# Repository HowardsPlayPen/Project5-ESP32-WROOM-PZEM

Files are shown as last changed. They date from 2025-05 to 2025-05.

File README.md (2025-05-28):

# Project 5: ESP32WROOM + some SMD soldering

So far, all my projects had involved modules for each component, such as using an ESP32-CAM, but I wanted to move to use more compact components - such as the ESP32-S2. The camera on the ESP32-CAM is amazing and simple to use - but for most of the projects I wanted to build having more GPIO pins available seemed like a better option.

At this point a friend sent me the following [link](https://twitter.com/i/status/1598419769077952512) showing an amazing PCB that was not much thicker than the PCB board but with a wonderul TFT screen built in

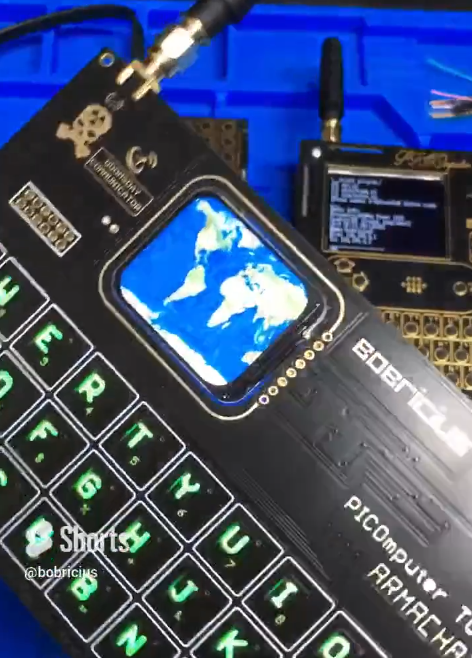
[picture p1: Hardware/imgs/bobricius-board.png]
Bobricus board


The twitter feed included a link to where you can buy the TFT on [AliExpress](https://www.aliexpress.com/item/1005003768946439.html)

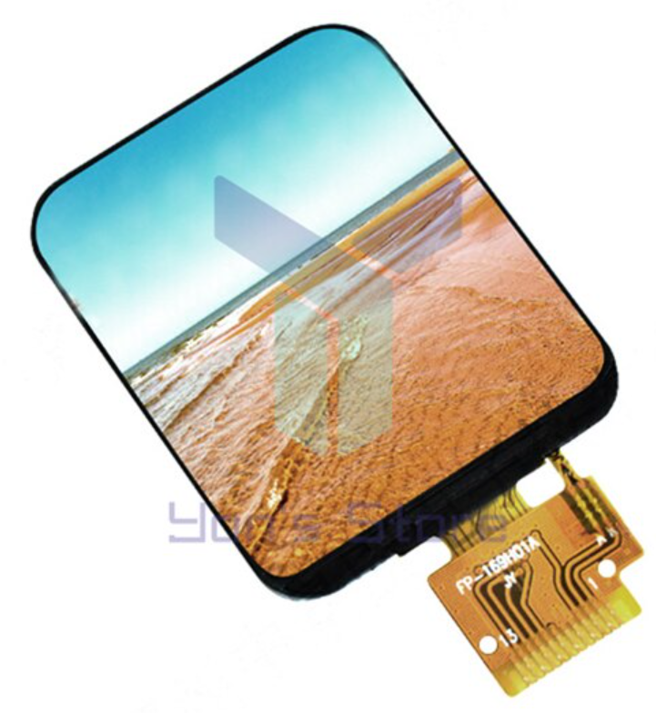
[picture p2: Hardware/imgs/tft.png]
TFT screen


Specs: 240*280 RGB Build-in ST7789 Driver Serial IPS Display

Note: this is **WAY** better than the SSD1306 I have been using which is a 0.96' screen 128x64 single colour screen

I wanted to try out these screens but I haven't soldered FPC cables before and so I bought several of these and one module that breaks out the wires into standard 2.54 mm pins. This way I could test the board to know it drives the panel ok before worrying about the FPC side

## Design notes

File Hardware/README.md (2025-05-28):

# Project5-ESP32-WROOM

Using an ESP32-WROOM + RFM69HW + PZEM + pinouts for a few different LED screens.

## Aim

Test out various different circuits - including touch buttons connected to ESP32 pins (I read that they could work as capacitative buttons)

It includes a connector for PZEM - i.e. ability to monitor 240V power use.

### PZEM v3
I bought my PZEM from Aliexpress but they are available everywhere, eg. [see here](https://esphome.io/components/sensor/pzemac.html)

PZEM v3 Board

## NOTE about OLED screen / board

> Note: this board does not connect BLK to 3V as the documentation said it was optional. This PCB works for the ST7789V2 boards that I have, but does not work for a newer ST7789V3 board where it **NEEDS**  BLK to be connected to 3V.

### Kicad Rendering of the PCB

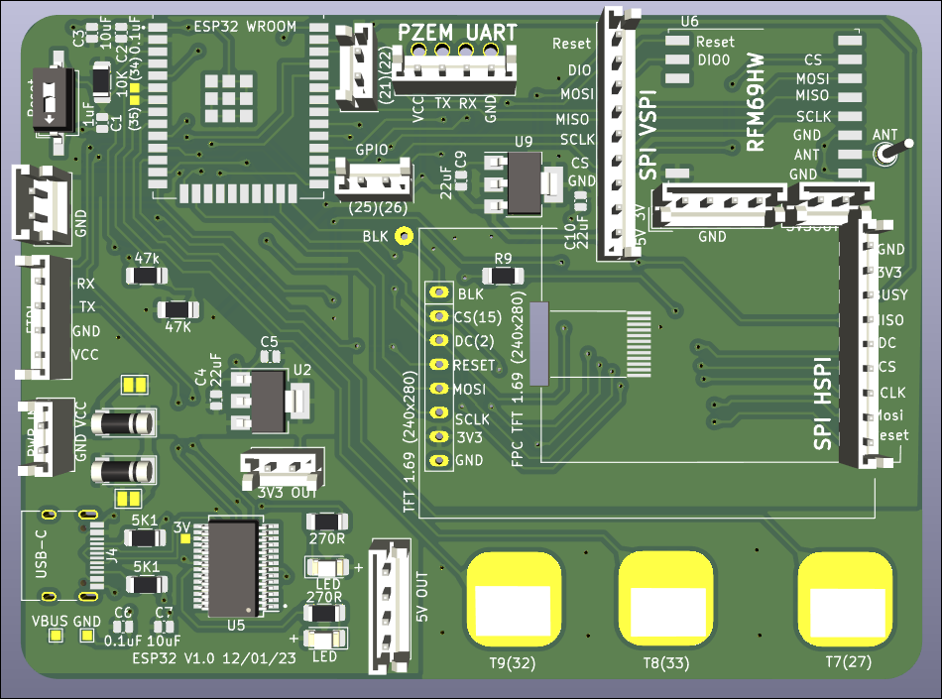
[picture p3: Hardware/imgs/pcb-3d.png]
Kicad rendered view of Finished board


### Kicad view of the PCB

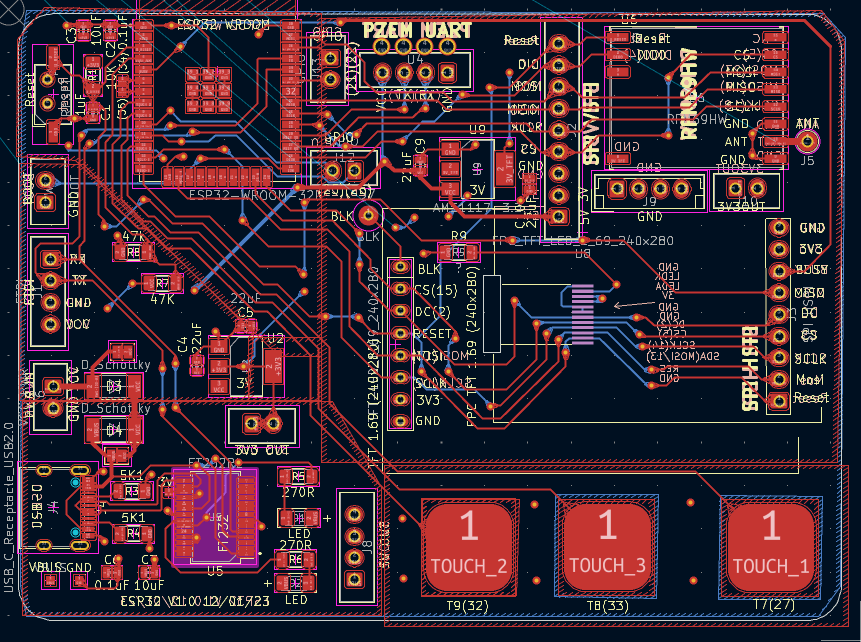
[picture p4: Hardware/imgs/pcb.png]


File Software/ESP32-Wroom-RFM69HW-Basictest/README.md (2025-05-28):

# Basic tests to evidence that the RFM69HW is connected properly to the board

For the RFM69HW to be working, it needs
1. power
2. correct wiring - e.g. GPIO  / hardware SPI (fallback to SPI is possible if I got the wiring wrong)
3. Reset working - currently should be connected to ESP32 reset on startup

At a software level, there is the choice of RFM69 library - I favour the RFM69 library by Felix Rusu ( https://github.com/LowPowerLab ) as I used it previously with Atmel examples, but the documentation states that the support of ESP32 is a best effort basis supported by separate developers (so I am not sure what to expect). I could also use the MySensors library (https://github.com/mysensors )- but at first glance I have not been filled with confidence that it will provide a library that is usable (only in that it is there to fulfil a purpose and if that purpose is not what you want then it did not feel as if the documentation was good enough to show you the best way to do things). Anyway, we shall soon see.....

Initially this project will test the Felix Rusu library and see how it works (or not..)

This project is working on the basis that earlier projects have been shown to work - e.g. wiring should be good + TFT screen is operational. This means that we can display lots of debug diagnostics on the screen to assist in establishing whether it all works.

## Project update

The first board I soldered was tested incrementally

1. first that the supporting circuitry worked - e.g power regulators / USB-C pins (these were crazy to solder!) - this was fine
2. add the ESP32 WROOM and check that it starts up with output being fed to RX / TX and that it can be flashed with new software - this worked fine
3. added the TFT screen and checked that worked (this uses the ESP32 hardware SPI of HSPI)  - this worked fine (so hence on to this Project to add the RFM69HW and test it)
4. adding the RFM69HW to the board - at this point the results started to go awry. The TFT screen did not work and neither did the RFM69HW - but the ESP32 was working perfectly fine 

I tried to debug the issue in both software and electronically but it was not obvious which element was causing the issue

1. it wasn't likely to be power related - i.e. if the RFM69HW was shorted or causing the voltage to dip too much then it is unlikely the ESP32 would work - so as the ESP32 was working I did not think this was the issue
2. the SPI pinouts were unconnected - e.g. using VSPI for RFM69HW and HSPI for TFT Screen so I could not see how adding the RFM69 could cause the previously working TFT to stop working (i.e. by having one wire cause a conflict)

I decided to solder up another board, both for practice but also with the aim to incrementally build it up again and see if the problem is replicated + at the same stage having the second board would also be useful if / when it was working, as one needs to have a test using **two** boards to see something transmit and something receive.

The second board worked better than the first
1. the first board did not play well with the software project - i.e. as a test I added a call to radio->readRegs() which should read all the contents of the RFM69 registers over SPI and dump them - but all it dumped were zero's. The second board dumped the following (showing an SPI  connection was seemingly working)

```
Address - HEX - BIN
1 - 4 - 100
2 - 0 - 0
3 - 2 - 10
4 - 40 - 1000000
5 - 3 - 11
6 - 33 - 110011
7 - 6C - 1101100
8 - 40 - 1000000
9 - 0 - 0
A - 41 - 1000001
B - 40 - 1000000
C - 2 - 10
D - 92 - 10010010
E - F5 - 11110101
F - 20 - 100000
10 - 24 - 100100
11 - 7F - 1111111
12 - 9 - 1001
13 - F - 1111
14 - 40 - 1000000
15 - B0 - 10110000
16 - 7B - 1111011
17 - 9B - 10011011
18 - 8 - 1000
19 - 42 - 1000010
1A - 8A - 10001010
1B - 40 - 1000000
1C - 80 - 10000000
1D - 6 - 110
1E - 10 - 10000
```
2. The TFT screen worked, even whilst the RFM69 was connected and operating (as shown above)

3. I tried to test the second board by flashing a transmitter test to an old Moteino board - which should ideally show some activity on my new ESP32 board + software Project, but I could not get any sign that it was transmitting or receiving anything. A simple call on the ESP32 to 

`radio->sendWithRetry(2, "START", 5,0,0);`

testing if the board would transmit did not work as expected as it never returned from this call (at least not in the 5 mins that I waited). 

**at this point (for now) I have decided to go down a different tack and order some new RA-01 Lora boards + update the PCB design to incorporate all the design issues + incorporate some new learning. I realise that I can spend a long time figuring out what is wrong - but in this case all I want is to get a LORA board working with an ESP32 and 'maybe' the better idea is to use a newer component (after all I have had the RFM68HW lying around for >5 years so maybe I should move on)**

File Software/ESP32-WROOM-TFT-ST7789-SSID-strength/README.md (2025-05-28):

# Purpose of this project is to test out the 1.69' TFT screen

Previous projects have helped to confirm whether the GPIO pins are correctly soldered  (and that the ESP32 is operational). 
This project includes the breakout version of the 1.69' TFT 240x RGB https://www.aliexpress.com/item/1005003754253714.html

It will help test:
1. whether all the pins for the TFT are correctly wired + soldered
2. are they correctly configured for the hardware SPI port of the ESP32 **VSPI**
3. once it is proven that we can use the hardware SPI VSPI then the included graphics tests (copied from Adafruit example) demonstrate various text drawing / line drawing routines

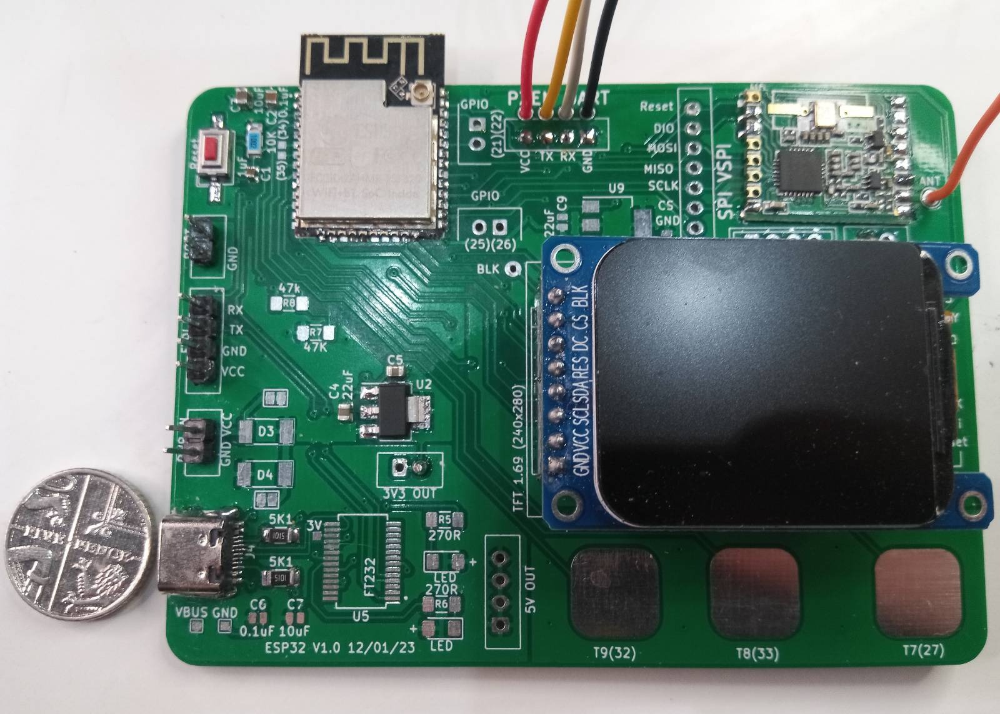
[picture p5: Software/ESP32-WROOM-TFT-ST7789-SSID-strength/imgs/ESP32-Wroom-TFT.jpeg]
Populated board ESP32 Board with mounted 1.69' TFT 240x280


**Once this project is working the board is known to have a working TFT, it can be used to display debug information for the next project.**

## Project update

The screen is an amazing screen and gives the ESP32 board a great way of displaying a weath of information in a rich way - far better than the .96' single colour TFT screen I used to use. By using the board version of the display I now have a working version to use as a benchmark - i.e. I can see how it is designed to hold the FPC display and what driving circuitry it uses. It also means that I know the circuit WILL work when I use the FPC TFT - i.e. always start from a known working premise (rtaher than use a never tested FPC TFT and then have too many unknowns when testing).

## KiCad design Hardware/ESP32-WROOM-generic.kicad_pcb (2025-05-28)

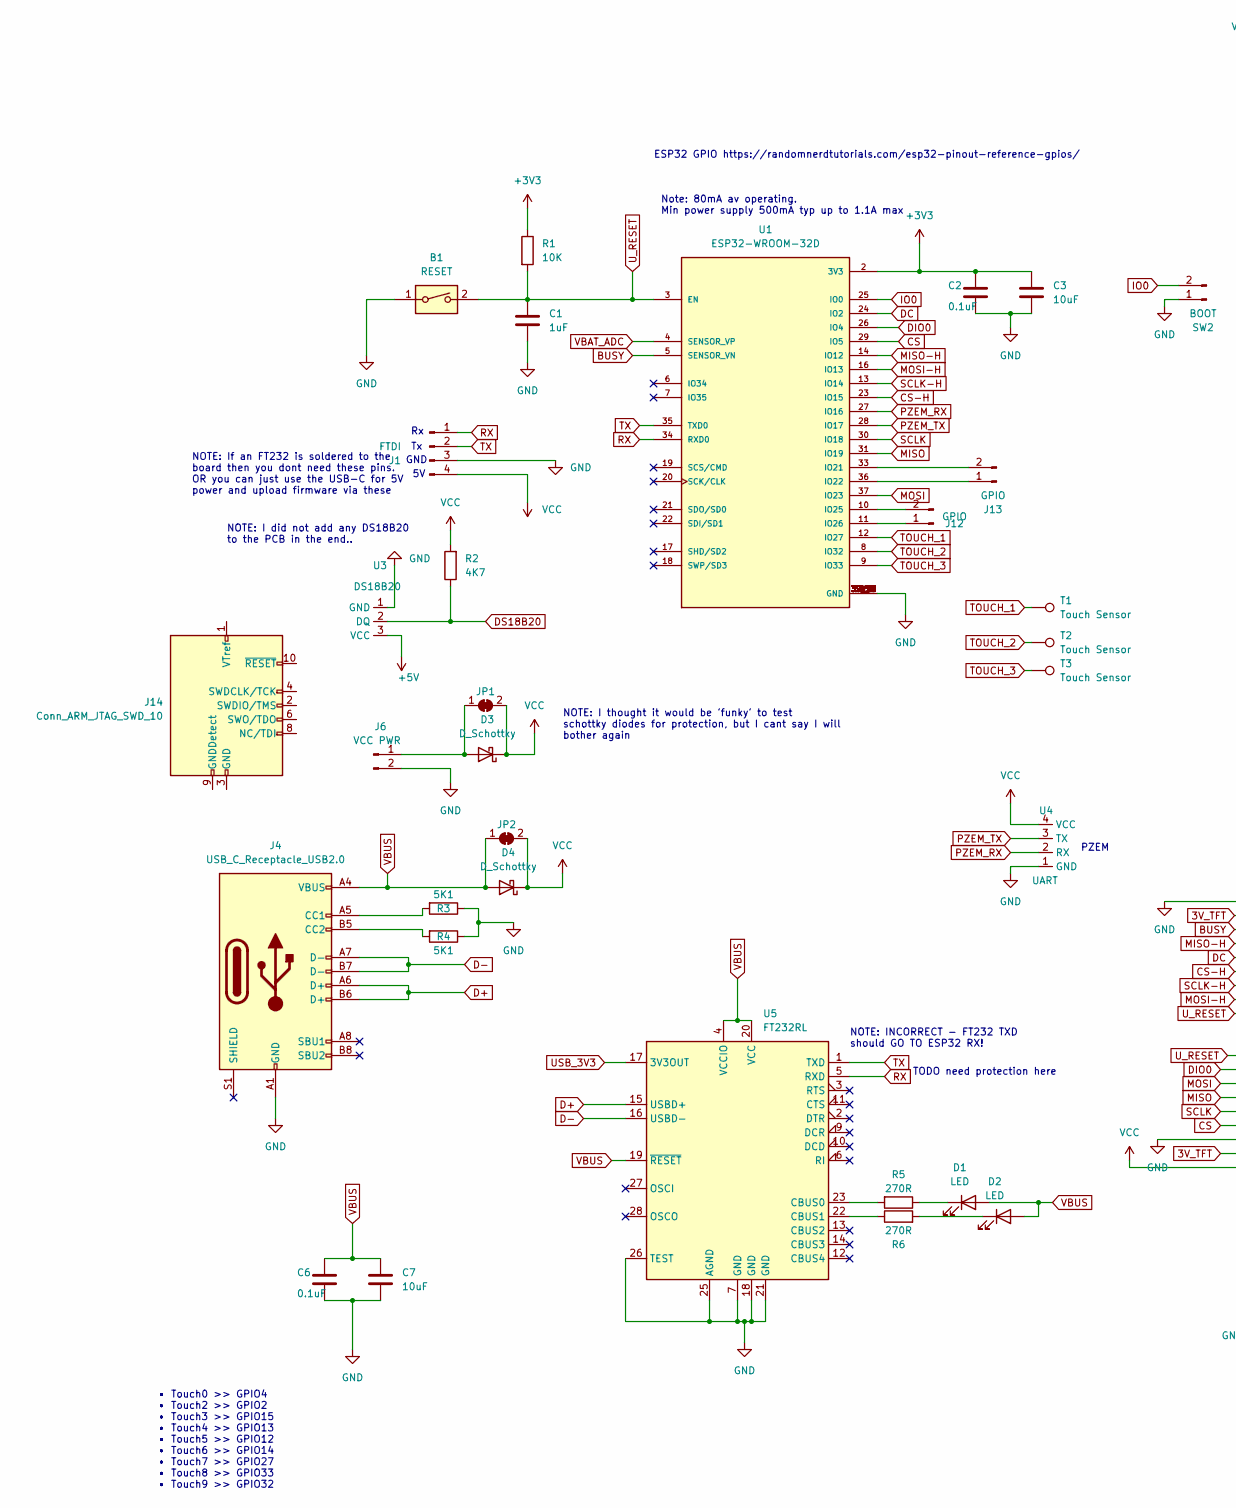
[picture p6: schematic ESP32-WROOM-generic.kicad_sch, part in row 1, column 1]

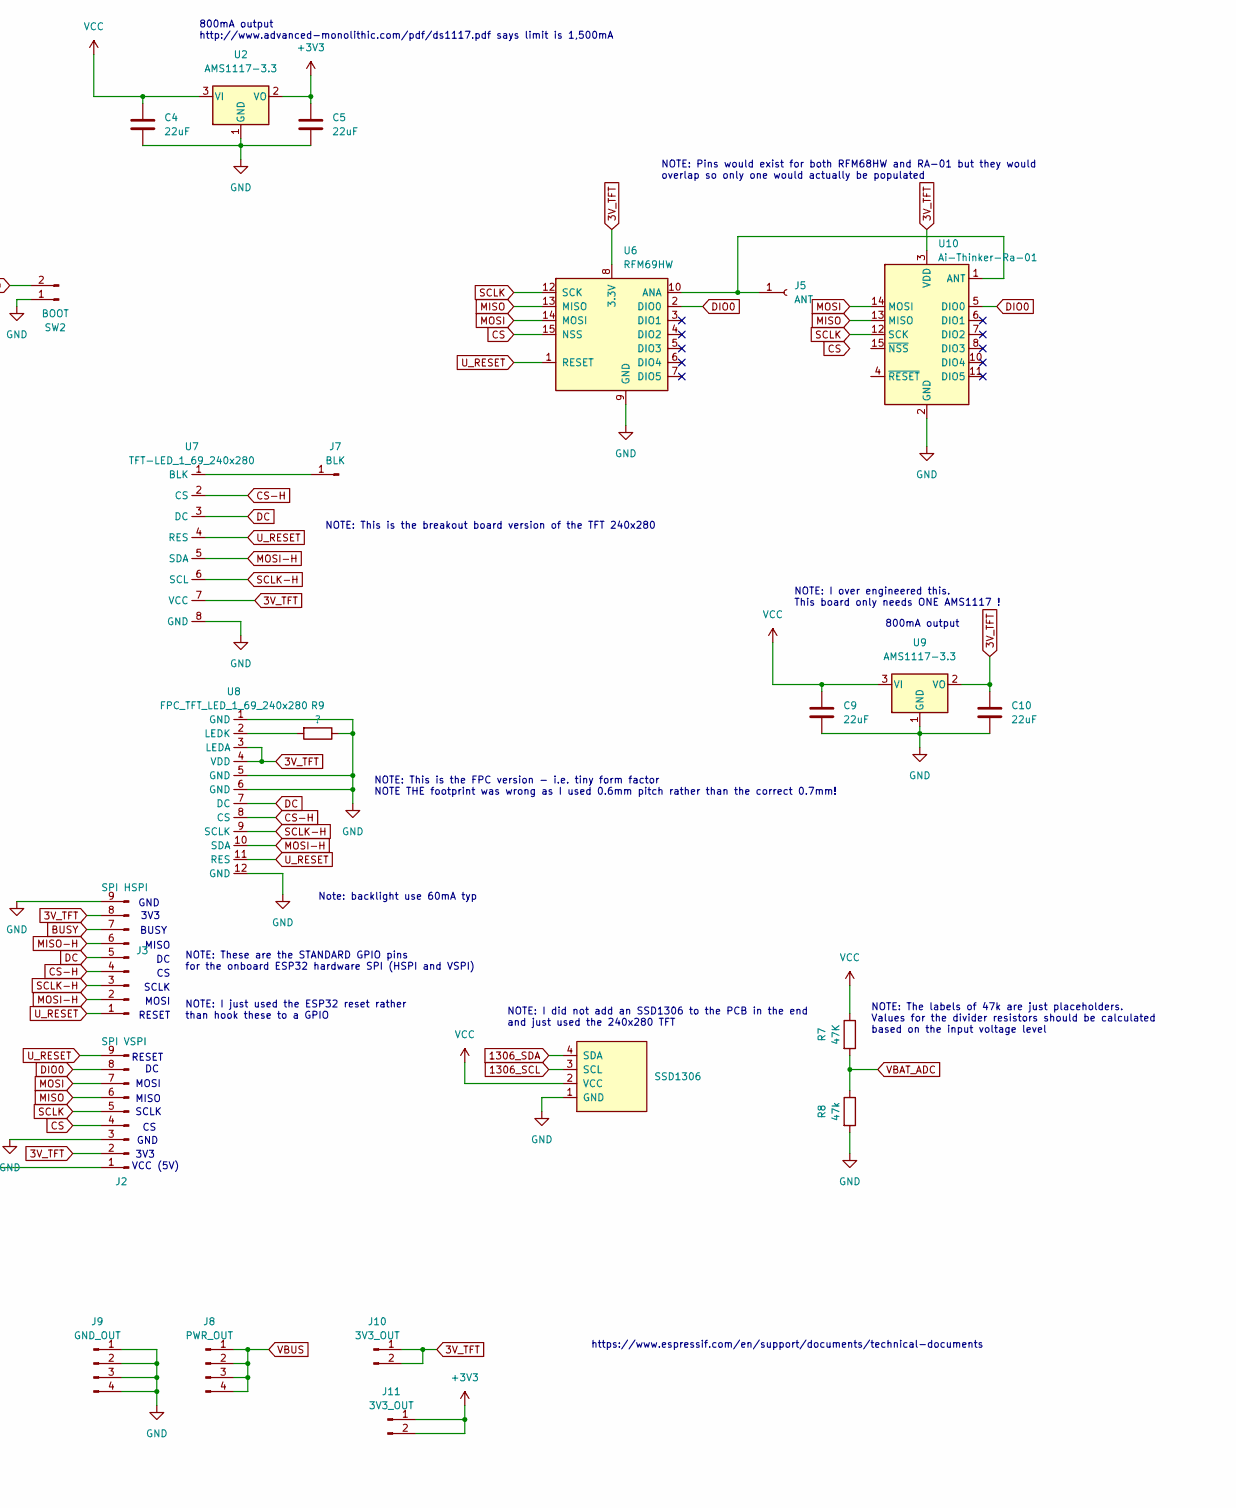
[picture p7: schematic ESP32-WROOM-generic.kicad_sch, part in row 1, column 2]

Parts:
B1: RESET; SW_DIP_SPSTx01_Slide_6.7x4.1mm_W8.61mm_P2.54mm_LowProfile
Brd1: SSD1306; 128x64OLED
C1: 1uF; C_0504_1310Metric_Pad0.83x1.28mm_HandSolder
C2, C6: 0.1uF; C_0504_1310Metric_Pad0.83x1.28mm_HandSolder
C3, C7: 10uF; C_0504_1310Metric_Pad0.83x1.28mm_HandSolder
C4, C5, C9, C10: 22uF; C_0504_1310Metric_Pad0.83x1.28mm_HandSolder
D1, D2: LED; LED_1206_3216Metric_Pad1.42x1.75mm_HandSolder
D3, D4: D_Schottky; D_MELF
J1: FTDI; JST_EH_B4B-EH-A_1x04_P2.50mm_Vertical
J2: SPI VSPI; JST_EH_B9B-EH-A_1x09_P2.50mm_Vertical
J3: SPI HSPI; JST_EH_B9B-EH-A_1x09_P2.50mm_Vertical
J4: USB_C_Receptacle_USB2.0; USB_C_Receptacle_HRO_TYPE-C-31-M-12
J5: ANT; Pin_D1.0mm_L10.0mm
J6: VCC PWR; JST_EH_B2B-EH-A_1x02_P2.50mm_Vertical
J7: BLK; TestPoint_Plated_Hole_D2.0mm
J8: PWR_OUT; JST_EH_B4B-EH-A_1x04_P2.50mm_Vertical
J9: GND_OUT; JST_EH_B4B-EH-A_1x04_P2.50mm_Vertical
J10, J11: 3V3_OUT; JST_EH_B2B-EH-A_1x02_P2.50mm_Vertical
J12, J13: GPIO; JST_EH_B2B-EH-A_1x02_P2.50mm_Vertical
J14: Conn_ARM_JTAG_SWD_10
JP1, JP2: SolderJumper_2_Bridged; SolderJumper-2_P1.3mm_Bridged_Pad1.0x1.5mm
R1: 10K; R_1206_3216Metric_Pad1.30x1.75mm_HandSolder
R2: 4K7; R_1206_3216Metric_Pad1.30x1.75mm_HandSolder
R3, R4: 5K1; R_1206_3216Metric_Pad1.30x1.75mm_HandSolder
R5, R6: 270R; R_1206_3216Metric_Pad1.30x1.75mm_HandSolder
R7: 47K; R_1206_3216Metric_Pad1.30x1.75mm_HandSolder
R8: 47k; R_1206_3216Metric_Pad1.30x1.75mm_HandSolder
R9: ?; R_1206_3216Metric_Pad1.30x1.75mm_HandSolder
SW2: BOOT; JST_EH_B2B-EH-A_1x02_P2.50mm_Vertical
T1, T2, T3: Touch Sensor; TestPoint_Pad_D4.0mm
U1: ESP32-WROOM-32D; MODULE_ESP32-WROOM-32D; PARTREV 1.9
U2, U9: AMS1117-3.3; SOT-223-3_TabPin2
U3: DS18B20; JST_NV_B03P-NV_1x03_P5.00mm_Vertical
U4: UART; JST_EH_B4B-EH-A_1x04_P2.50mm_Vertical
U5: FT232RL; SSOP-28_5.3x10.2mm_P0.65mm
U6: RFM69HW; HOPERF_RFM69HW
U7: TFT-LED_1_69_240x280
U8: FPC_TFT_LED_1_69_240x280; FPC_TFT_1_69_240x280
U10: Ai-Thinker-Ra-01; Ai-Thinker-Ra-01-LoRa

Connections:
3V_TFT: C10.1, J2.2, J3.8, J10.1, J10.2, U6.8 (3.3V), U7.7 (VCC), U8.3 (LEDA), U8.4 (VDD), U9.2 (VO), U10.3 (VDD)
+3V3: C2.1, C3.1, C5.1, J11.1, J11.2, R1.1, U1.2 (3V3), U2.2 (VO)
BUSY: J3.7, U1.5 (SENSOR_VN)
CS: J2.4, U1.29 (IO5), U6.15 (NSS)
CS-H: J3.4, U1.23 (IO15), U7.2 (CS), U8.8 (CS)
D+: J4.A6 (D+), J4.B6 (D+), U5.15 (USBD+)
D-: J4.A7 (D-), J4.B7 (D-), U5.16 (USBD-)
DC: J3.5, U1.24 (IO2), U7.3 (DC), U8.7 (DC)
DIO0: J2.8, U1.26 (IO4), U6.2 (DIO0), U10.5 (DIO0)
GND: B1.1, Brd1.1 (GND), C1.2, C2.2, C3.2, C4.2, C5.2, C6.2, C7.2, C9.2, C10.2, J1.3, J2.3, J3.9, J4.A1 (GND), J4.A12 (GND), J4.B1 (GND), J4.B12 (GND), J6.2, J9.1, J9.2, J9.3, J9.4, R3.1, R4.1, R8.2, R9.1, SW2.1, U1.1 (GND), U1.15 (GND), U1.38 (GND), U1.39_1 (GND), U1.39_2 (GND), U1.39_3 (GND), U1.39_4 (GND), U1.39_5 (GND), U1.39_6 (GND), U1.39_7 (GND), U1.39_8 (GND), U1.39_9 (GND), U1.39_10 (GND), U1.39_11 (GND), U1.39_12 (GND), U1.39_13 (GND), U1.39_14 (GND), U1.39_15 (GND), U1.39_16 (GND), U1.39_17 (GND), U1.39_18 (GND), U1.39_19 (GND), U1.39_20 (GND), U1.39_21 (GND), U2.1 (GND), U3.1 (GND), U4.1 (GND), U5.7 (GND), U5.18 (GND), U5.21 (GND), U5.25 (AGND), U5.26 (TEST), U6.9 (GND), U6.11 (GND), U7.8 (GND), U8.1 (GND), U8.5 (GND), U8.6 (GND), U8.12 (GND), U9.1 (GND), U10.2 (GND), U10.9 (GND), U10.16 (GND); also elsewhere on the board
IO0: SW2.2, U1.25 (IO0)
MISO: J2.6, U1.31 (IO19), U6.13 (MISO), U10.13 (MISO)
MISO-H: J3.6, U1.14 (IO12)
MOSI: J2.7, U1.37 (IO23), U6.14 (MOSI), U10.14 (MOSI)
MOSI-H: J3.2, U1.16 (IO13), U7.5 (SDA), U8.10 (SDA)
unnamed: D1.1 (K), R5.1
unnamed: D2.1 (K), R6.2
unnamed: D3.2 (A), J6.1, JP1.1 (A)
unnamed: J4.A5 (CC1), R3.2
unnamed: J4.B5 (CC2), R4.2
unnamed: J5.1, U6.10 (ANA), U10.1 (ANT)
unnamed: J7.1, U7.1 (BLK)
unnamed: J12.1, U1.11 (IO26)
unnamed: J12.2, U1.10 (IO25)
unnamed: J13.1, U1.36 (IO22)
unnamed: J13.2, U1.33 (IO21)
unnamed: J14.3 (GND), J14.5 (GND)
unnamed: R2.1, U3.2 (DQ)
unnamed: R5.2, U5.23 (CBUS0)
unnamed: R6.1, U5.22 (CBUS1)
unnamed: R9.2, U8.2 (LEDK)
PZEM_RX: U1.27 (IO16), U4.2 (RX)
PZEM_TX: U1.28 (IO17), U4.3 (TX)
RX: J1.1, U1.34 (RXD0), U5.5 (RXD)
SCLK: J2.5, U1.30 (IO18), U6.12 (SCK), U10.12 (SCK)
SCLK-H: J3.3, U1.13 (IO14), U7.6 (SCL), U8.9 (SCLK)
TOUCH_1: T1.1, U1.12 (IO27)
TOUCH_2: T2.1, U1.8 (IO32)
TOUCH_3: T3.1, U1.9 (IO33)
TX: J1.2, U1.35 (TXD0), U5.1 (TXD)
USB_3V3: U5.17 (3V3OUT)
U_RESET: B1.2, C1.1, J2.9, J3.1, R1.2, U1.3 (EN), U6.1 (RESET), U7.4 (RES), U8.11 (RES)
VBAT_ADC: R7.2, R8.1, U1.4 (SENSOR_VP)
VBUS: C6.1, C7.1, D1.2 (A), D2.2 (A), D4.2 (A), J4.A4 (VBUS), J4.A9 (VBUS), J4.B4 (VBUS), J4.B9 (VBUS), J8.1, J8.2, J8.3, J8.4, JP2.1 (A), U5.4 (VCCIO), U5.19 (~RESET), U5.20 (VCC); also elsewhere on the board
VCC: Brd1.2 (VCC), C4.1, C9.1, D3.1 (K), D4.1 (K), J1.4, J2.1, JP1.2 (B), JP2.2 (B), R2.2, R7.1, U2.3 (VI), U4.4 (VCC), U9.3 (VI)

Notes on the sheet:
RESET
NOTE: I over engineered this. This board only needs ONE AMS1117 !
Note: backlight use 60mA typ
NOTE: If an FT232 is soldered to the board then you dont need these pins. OR you can just use the USB-C for 5V power and upload firmware via these
NOTE: This is the FPC version - i.e. tiny form factor NOTE THE footprint was wrong as I used 0.6mm pitch rather than the correct 0.7mm!
NOTE: The labels of 47k are just placeholders. Values for the divider resistors should be calculated based on the input voltage level
NOTE: These are the STANDARD GPIO pins for the onboard ESP32 hardware SPI (HSPI and VSPI)
NOTE: I did not add any DS18B20 to the PCB in the end..
VCC (5V)
MOSI
ESP32 GPIO https://randomnerdtutorials.com/esp32-pinout-reference-gpios/
• Touch0 >> GPIO4 • Touch2 >> GPIO2 • Touch3 >> GPIO15 • Touch4 >> GPIO13 • Touch5 >> GPIO12 • Touch6 >> GPIO14 • Touch7 >> GPIO27 • Touch8 >> GPIO33 • Touch9 >> GPIO32
MISO
800mA output http://www.advanced-monolithic.com/pdf/ds1117.pdf says limit is 1,500mA
GND
3V3
TODO need protection here
NOTE: I thought it would be 'funky' to test schottky diodes for protection, but I cant say I will bother again
NOTE: Pins would exist for both RFM68HW and RA-01 but they would overlap so only one would actually be populated
800mA output
SCLK
NOTE: I did not add an SSD1306 to the PCB in the end and just used the 240x280 TFT
NOTE: INCORRECT - FT232 TXD should GO TO ESP32 RX!
NOTE: This is the breakout board version of the TFT 240x280
PZEM
Note: 80mA av operating. Min power supply 500mA typ up to 1.1A max
https://www.espressif.com/en/support/documents/technical-documents
NOTE: I just used the ESP32 reset rather than hook these to a GPIO
BUSY

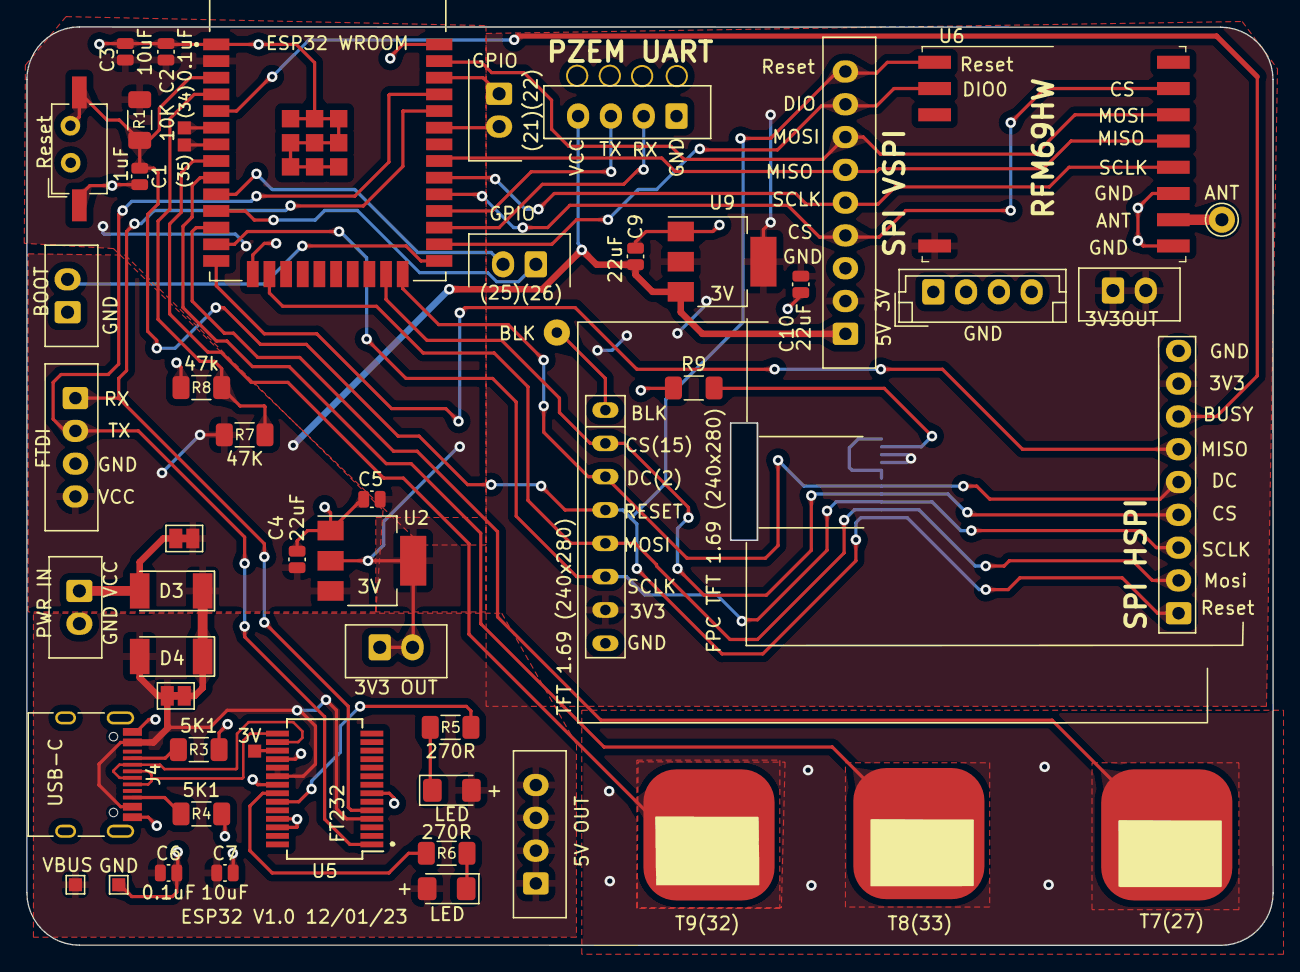
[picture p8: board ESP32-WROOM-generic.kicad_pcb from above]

Board: 2 copper layers, 95.0 x 70.0 mm, 51 parts (0 on the bottom side), 42 nets.

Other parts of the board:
GND: TestPoint_Pad_1.0x1.0mm
VBUS: TestPoint_Pad_1.0x1.0mm

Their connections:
GND: GND.1; also elsewhere on the board
VBUS: VBUS.1; also elsewhere on the board

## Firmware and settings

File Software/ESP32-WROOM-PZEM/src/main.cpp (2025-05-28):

/// Project to use the newest PCB with a ESP32-WROOM and a TFT 1.69' screen 240z280 along with a PZEM-004T in order
/// to monitor the power / electric usage in our household and transmit the information over MQTT
/// It will show information on the TFT screen - such as line charts of power usage etc

/// The aim is to use both CPU cores - one for the PZEM monitoring and display and the other for monitoring 
/// the network side / the MQTT connection and capacitiative touch buttons


#define ARDUINOJSON_ENABLE_COMMENTS 1
#include <Arduino.h>
#include <WiFi.h>

#include <SPI.h>
#include <Wire.h>
#include <Adafruit_GFX.h>
#include <Adafruit_ST7789.h> // Hardware-specific library for ST7789

#include <SparkLine.h>

/// Used for the simple MQTT publisher
#include <PubSubClient.h>

#include "ssdp_helper.hpp"

#include <PsychicHttp.h>
#include <ElegantOTA.h>
#include <WiFi.h>

#include "json_settings.hpp"
#include "ota_default.hpp"

/// Below are the PZEM specific bits - i.e. initialising the right GPIO to use etc
#include <HardwareSerial.h>

// The below "define" controls whether it uses the V3 or V2 serial interface (which depends on which PZEM-004T board you have).
// V3 outputs a few extra parameters and the board has leds that pulse when readings are being taken
#define PZEM_V3


/// NOTE 10.0.1.75 - solar monitor
/// NOTE 10.0.1.7 - house 240V monitor

//#define SOLAR

#ifdef PZEM_V3
/// The below include is when we have a NEW version of PZEM (v3)
#include <PZEM004Tv30.h> // See https://github.com/mandulaj/PZEM-004T-v30

#else
// This is for the OLDER version of PZEM (v2.0)
#include <PZEM004T.h>   // See https://github.com/olehs/PZEM004T
#endif

#include <memory>
#include <vector>


//Hardware Serial on two GPIO
/// CONNECT (ESP32 RX) to TX on PZEM
/// CONNECT (ESP32 TX) to RX on PZEM
#define RX2 16
#define TX2 17



// On the ESP32 there are two HARDWARE SPI ports - one called VSPI (default) and the other HSPI
// On my board, HSPI will be used for the TFT LCD and VSPI is used for RFM68HW 
// The board is using the STANDARD defined pins for HSPI (so in a way the following defines are redundant)
#define HSPI_MISO   12
#define HSPI_MOSI   13
#define HSPI_SCLK   14
#define HSPI_SS     15

// This is a board specific pin number - i.e. for this TFT we need a DC pin and I have designed the PCB with it on GPIO 2
#define TFT_DC 2

HardwareSerial SerialPZEM( 2 ); // ESP32 has 3 hardware serials - 0 is used for FTDI / UART, we will use the 3rd one


#ifdef PZEM_V3

PZEM004Tv30 pzem(SerialPZEM,RX2,TX2);

#else
PZEM004T pzem(&Serial2,RX2,TX2);

IPAddress ip(192,168,1,1); // For some reason the older version of the PZEM library wants to be given an IP address so we assign a random one...

#endif

// Define the REST server instance
PsychicWebSocketHandler websocketHandler;
PsychicEventSource eventSource;
PsychicHttpServer server;


// Rest endpoint to allow resetting of the accumulated power meter in the PZEM 
esp_err_t reset_pzem(PsychicRequest *request)
{
  PsychicResponse response(request);
  response.setCode(200);
  response.setContentType("text/json");

  bool ret = pzem.resetEnergy();
  
  const char * txt = ret ? "{\"reset\":\"true\"}" : "{\"reset\":\"false\"}";
  response.setContent((const uint8_t*)txt,strlen(txt));
  return response.send();
}


// Enum to keep track of the current state for each button
enum TouchState {TouchUndefined, ButtonUp, ButtonFirstPress, ButtonPressed, ButtonDown};

/// Note: The TFT / SPI api has param for  a reset pin - but for this board I have connected RESET of TFT to the "enable" pin of the ESP32 - i.e. it resets upon startup
struct core1_state
{  
  //uninitalised pointers to SPI objects
  SPIClass * hspi = NULL;
  Adafruit_ST7789 * tft = NULL; 

  bool isDirty = true; // Does the screen need a refresh

  uint8_t pzemAddress = 0;
  float voltage=0.0;
  float current=0.0;
  float power=0.0;
  float energy=0.0;
  float frequency=0.0;
  float pf=0.0;

  int pageNumber = 0; // We have multiple pages for display in this app - changed by pressing the capacitative 'touch' button

  bool pzemConnected = false;

  /// Sparklines let us draw simple 2d line charts that update as new values are pushed in - this will show the power usage
  std::shared_ptr<SparkLine<uint16_t> > powerUsage; // Keep track of the latest X values (where X is set in the constructor below)

};

struct core2_state
{
  bool networkConnected = false;
  bool mqttConnected = false;

  /// MQTT details
  String mqtt_server = "";

  String mqtt_user = "iot"; // Again, this is hardwired to an MQTT user on Pidesktop1
  String mqtt_password = "iot1";

  String mqtt_topicOUT ="/esp32/Electricity/";

  /// TEMPORARY HACK - FOR NOW I KNOW THAT THE PZEM IN THE HOUSE IS V3 and is for the household power and the
  /// PZEM in the workshop is V2 and for monitoring the solar - hence this temporary hardwiring...
#ifndef SOLAR
  String mqtt_topicName = "house";   // "house" for the household power usage and "solar" for the Solar PV generated power
#else
  String mqtt_topicName = "solar";   // "house" for the household power usage and "solar" for the Solar PV generated power
#endif
  String mqtt_port  = "1883";  

  char mqtt_client_id[23]; // This is auto generated in connection functions below 
  std::vector< std::pair< String, int32_t> > ssidList;

  String ssdp_name;
  String ssdp_modelname;
};


bool setup_mqtt();
void mqtt_callback(char* topic, byte* payload, unsigned int length);
void reconnectMQTT(int retryCount);

const int numberTouchPins = 3; /// Ensure this value is consistent with the C array below
const int touchPins[]={T9,T8,T7}; 
bool touchPinsState[] = {false,false,false}; // Keep track of the read in value

TouchState touchPinsInternalState[] = {TouchUndefined,TouchUndefined,TouchUndefined};

const uint16_t touchPressThreshold = 20; // Magic number:  This is determined / calibrated by doing a simple runtime test of the board and seeing what is returned from touchRead()

/// Main state variables
core1_state tftState;
core2_state networkState;
TaskHandle_t Task1;  // Second thread for managing network / mqtt and touch buttons

WiFiClient espClient;
PubSubClient mqttClient(espClient);

// Simple handler for index page 
esp_err_t get_index_html(PsychicRequest *request)
{
  PsychicResponse response(request);
  response.setCode(200);
  response.setContentType("text/json");

  String json = "{\"v\":" + String(tftState.voltage) + "}";   
  response.setContent((const uint8_t*)json.c_str(),json.length());
  return response.send();
}


void NetworkThreadCode( void * parameter); // Fwd declare function for the second thread
void extractPZEM_Info();

void displayPage0(bool fullRedraw)
{
  if(fullRedraw)
  {
    tftState.tft->fillScreen(ST77XX_BLACK);
  }
  tftState.tft->setTextColor(ST77XX_WHITE,ST77XX_BLACK);

  tftState.tft->setCursor(35, 2);
  tftState.tft->setTextSize(2);
  tftState.tft->println("0");


  tftState.tft->setCursor(65, 2);
  tftState.tft->setTextSize(2);
  tftState.tft->println("ETH");
  uint16_t col = networkState.networkConnected ? ST77XX_GREEN : ST77XX_RED;
  tftState.tft->fillRect(105,2,20,20,col);

  tftState.tft->setCursor(135, 2);
  tftState.tft->setTextSize(2);
  tftState.tft->println("MQTT");
  col = networkState.mqttConnected ? ST77XX_GREEN : ST77XX_RED;
  tftState.tft->fillRect(185,2,20,20,col);  

/// PZEM address looks pretty bland so removing it from the display (for now?)

  tftState.tft->setTextSize(2); 
  tftState.tft->setCursor(0,25); 
  tftState.tft->print(String(tftState.pzemAddress));


  tftState.tft->setTextSize(3);
  tftState.tft->setCursor(0,50); 
  tftState.tft->print(String(tftState.voltage) + " V");

  tftState.tft->setCursor(0,90); 
  tftState.tft->print(String(tftState.current) + " A");

  tftState.tft->setCursor(0,130); 
  tftState.tft->print(String(tftState.power) + " W");

  tftState.tft->setCursor(120,130); 
  tftState.tft->print(String(tftState.energy) + " VA");

#ifdef PZEM_V3
  tftState.tft->setCursor(0,160); 
  tftState.tft->print(String(tftState.frequency) + " Hz");

  tftState.tft->setCursor(0,190); 
  tftState.tft->print(String(tftState.pf) + " PF");
#endif  

  //if(!tftState.pzemConnected)
  {
    tftState.tft->setCursor(210, 2);
    tftState.tft->setTextSize(2);
#ifdef PZEM_V3    
    tftState.tft->println("P3");  
#else
    tftState.tft->println("P2");  
#endif
    col = tftState.pzemConnected ? ST77XX_GREEN : ST77XX_RED;
    tftState.tft->fillRect(235,2,20,20,col);  
  }

  
  tftState.tft->setCursor(160, 220);
  tftState.tft->setTextSize(2);
  String ip = WiFi.localIP().toString();
  tftState.tft->println(ip);
}

void displayPage1(bool fullRedraw)
{
  // Always do a full refresh as we are showing a line graph that will update frequently
  //if(fullRedraw)
  {
    tftState.tft->fillScreen(ST77XX_ORANGE);
  }

  tftState.tft->setTextColor(ST77XX_WHITE, ST77XX_ORANGE);

  tftState.tft->setCursor(35, 2);
  tftState.tft->setTextSize(2);
  tftState.tft->println("1");

  // Display the sparkline 2d line graph showing power usage information
  if(tftState.powerUsage)
  {              
      tftState.tft->setTextSize(3);
      tftState.powerUsage->draw(5, 230, 260, 220);
      tftState.tft->setCursor(2,22);
      tftState.tft->print(String(tftState.power));
  }

}

void displayPage2(bool fullRedraw)
{
  if(fullRedraw)
  {
    tftState.tft->fillScreen(ST77XX_ORANGE);
  }

  tftState.tft->setTextColor(ST77XX_WHITE, ST77XX_ORANGE);

  tftState.tft->setCursor(35, 2);
  tftState.tft->setTextSize(2);
  tftState.tft->println("2");

  int y = 50;

  for(int ctr=0; ctr< networkState.ssidList.size(); ++ctr)
  {
    const std::pair<String, int32_t> & item(networkState.ssidList[ctr]);

    tftState.tft->setCursor(10, y);
    tftState.tft->print( item.first);

    tftState.tft->setCursor(220, y);
    tftState.tft->print( item.second);
    
    y+= 20;
  }


}

unsigned long lastDisplay = 0;

// Display loop for the TFT screen - there are multiple pages of info that can be shown
void display(unsigned long now, bool fullRedraw)
{
  if(!tftState.isDirty)
  {
    return;
  }

  if((now - lastDisplay) < 200)
  {
    return;
  }

  lastDisplay = now; // Only refresh every 100ms max

  tftState.isDirty = false;

  switch(tftState.pageNumber)
  {
    case 0:
    displayPage0(fullRedraw);
    break;

    case 1:
    displayPage1(fullRedraw);
    break;

    case 2:
    default:
    displayPage2(fullRedraw);
    break;
  }
}


bool fullRedraw = false;

void setup()
{
  Serial.begin(115200);

  // pinMode(TX2, OUTPUT);  // Set GPIO as output
  // pinMode(RX2, INPUT);   // Set GPIO as input

  Serial.print(F("ESP32-WROOM-PZEM Startup on Core "));
  Serial.println(xPortGetCoreID());

  //initialise an instance of the SPIClass attached to HSPI respectively
  tftState.hspi = new SPIClass(HSPI);
  
  //initialise hspi with default pins
  //SCLK = 14, MISO = 12, MOSI = 13, SS = 15
  tftState.hspi->begin();

  tftState.tft = new Adafruit_ST7789(tftState.hspi,HSPI_SS, TFT_DC, -1);
  tftState.tft->init(240, 280);           // Init ST7789 280x240
  // default rotation is if the screen was rotated 90 deg clockwise
  // rotation 1 is upside down
  // rotation 2 is rotated 90 anti-clockwise
  tftState.tft->setRotation(3);

  tftState.tft->fillScreen(ST77XX_RED);
  Serial.println(F("TFT initialised - reading "));

  JsonDocument doc;
  if(!LoadJsonSettings(doc))
  {
      /// TODO HANDLE THIS ERROR - e.g. FLASH THE LED
      Serial.println("ERROR: Investigate what went wrong in loading JSON file");
  }

  JsonObject root = doc.as<JsonObject>();

  if(!LoadDefaultParameters(root))
  {
    //// TODO HANDLE THIS ERROR
    Serial.println("ERROR: Investigate what went wrong in processing the JSON object");
  }

  try
  {
    networkState.ssdp_name      =   root["ssdp_name"].as<String>();
    networkState.ssdp_modelname =   root["ssdp_modelname"].as<String>();

    Serial.printf("SSDP Name: (%s), model name (%s)",networkState.ssdp_name.c_str(), networkState.ssdp_modelname.c_str());
    Serial.println("");

    String tmp = root["mqtt_server"].as<String>();

    if(tmp.length())
      networkState.mqtt_server  = tmp;
    
    tmp = root["mqtt_user"].as<String>();

    if(tmp.length())
      networkState.mqtt_user     = tmp;

    tmp = root["mqtt_password"].as<String>();
    
    if(tmp.length())
      networkState.mqtt_password = tmp;

    Serial.printf("MQTT Server: (%s), User (%s), Password (%s)",networkState.mqtt_server.c_str(), networkState.mqtt_user.c_str(), networkState.mqtt_password.c_str());
    Serial.println("");
  }
  catch(const std::exception& e)
  {
    Serial.println(e.what());
  }
  
  Serial.println(F("Starting Network thread"));
  xTaskCreatePinnedToCore(
      NetworkThreadCode, /* Function to implement the task */
      "Network", /* Name of the task */
      10000,  /* Stack size in words */
      NULL,  /* Task input parameter */
      0,  /* Priority of the task */
      &Task1,  /* Task handle. */
      0); /* Core where the task should run */

  Serial.println("CORE1: Setup PZEM");
  // Quite possible that the PZEM instance has already initialised the hardware serial at this point.
  SerialPZEM.begin(9600,SERIAL_8N1,RX2,TX2);  

#ifdef PZEM_V3

#else
  pzem.setAddress(ip);
#endif

  Serial.println("CORE1: Initialised HW Serial");

  Serial.println(pzem.readAddress(), HEX);

  delay(100);

  // Serial.println(F("CORE1: Reset energy"));
  // pzem.resetEnergy();

  Serial.println(F("CORE1: End setup"));
  fullRedraw=true;
}


unsigned long lastPZEMSample=0; // milli second at which we took a PZEM reading

// Main loop for one thread (running on Core 1)
void loop() { 
  
  unsigned long now = millis();

  // Scan through Touch pins
  for(int counter=0; counter<numberTouchPins; ++counter)
  {
    uint16_t touch_sensor = touchRead(touchPins[counter]);     

    if(touch_sensor < touchPressThreshold)
    {
      switch(touchPinsInternalState[counter])
      {
        case TouchUndefined:
        case ButtonUp:
        default:
          touchPinsInternalState[counter] = ButtonFirstPress; // Button must be pressed for two cycles to become 'ButtonDown' - to stop fake presses          
          break;
        case ButtonFirstPress:
          touchPinsInternalState[counter] = ButtonPressed;
          touchPinsState[counter] = true;
          break;
        case ButtonPressed:
          // We differentiate between when the button is first pressed and then separately being held down
          touchPinsInternalState[counter] = ButtonDown;
          break;

        case ButtonDown:
          // Do nothing as button is still being pressed
          break;
      }
    }
    else
    {
      touchPinsInternalState[counter] = ButtonUp;
    }
  }

  if(touchPinsState[0])
  {    
    touchPinsState[0] = false; // Reset the state 
    ++tftState.pageNumber;
    tftState.isDirty = true;
    fullRedraw = true;

    if(tftState.pageNumber >2)
    {
      tftState.pageNumber = 0;
    }
  }

  if(!SerialPZEM)
  {
     Serial.println("HWSerialPZEM not initialised");
  }

  if(SerialPZEM && pzem.isConnected() ) //!tftState.pzemConnected)
  {
    tftState.pzemConnected = true;      
  }

  // Only sample the power information every second max
  if(tftState.pzemConnected && ((now - lastPZEMSample) > 1000))
  {
    lastPZEMSample = now;
    extractPZEM_Info();
  }

  display(now, fullRedraw); 
  fullRedraw = false;

  delay(50);
}

void scanNetworks() {
 
  // TODO - this makes a race condition between this thread scanning the SSIDs and the display function
  networkState.ssidList.clear();

  int numberOfNetworks = WiFi.scanNetworks();
 
  Serial.print("Number of networks found: ");
  Serial.println(numberOfNetworks);
 
  for (int i = 0; i < numberOfNetworks; i++) {
 
    Serial.print("Network name: ");
    Serial.println(WiFi.SSID(i));
 
    Serial.print("Signal strength: ");
    Serial.println(WiFi.RSSI(i));  

    networkState.ssidList.push_back( std::make_pair(WiFi.SSID(i),WiFi.RSSI(i)));
  }
}

void setup_network()
{
  scanNetworks();
  tftState.isDirty = true;

  WiFi.mode(WIFI_STA);
  WiFi.begin(ssid, password); // These were loaded from the JSON settings file.
  Serial.println("Connected");

  // Wait for connection
  while (WiFi.status() != WL_CONNECTED) {
    delay(500);
    Serial.print(".");
  }
  Serial.println("");
  Serial.print("Connected to ");
  Serial.println(ssid);
  Serial.print("IP address: ");
  Serial.println(WiFi.localIP());

  networkState.networkConnected = WiFi.status() == WL_CONNECTED;
  tftState.isDirty = true;   
}


// Main loop for second thread (running on Core 0) - this function should not exit as that would cause the ESP32 to abort and reboot(!)
void NetworkThreadCode( void * parameter)
{
  Serial.println(F("Second thread initialised + running on Core "));
  Serial.println(xPortGetCoreID());

  // Startup initialisation code first
  setup_network();

  Serial.print("WIFI configured ");
  Serial.println(WiFi.status() == WL_CONNECTED);

  setup_mqtt(); // TODO should check if network is ok etc
  networkState.mqttConnected = mqttClient.connected();
  tftState.isDirty = true; 

    // Set Authentication Credentials
   ElegantOTA.setAuth(ota_user.c_str(), ota_password.c_str());
  // start server
  server.listen(80); // MUST call listen() before registering any urls using .on()

  ssdp_helper params{"/update",networkState.ssdp_name,"Esp32",networkState.ssdp_modelname,"https://aitchpea.com"};
  
  setup_ssdp(params,server);  // REMEMBER must call thios AFTER server.lkisten()

  server.on("/", HTTP_GET, get_index_html);

  server.on("/reset", HTTP_GET, reset_pzem);

  // The below function registers a handler with the Web server to generically handle HTTP_OPTIONS and add the flags that we are not worried about CORS
  disable_cors(server); // CORS is pointless for an IOT device here

  // Note: ElegantOTA listens on the url "/update"
  ElegantOTA.begin(&server);    // Start ElegantOTA

  //ElegantOTA callbacks
  ElegantOTA.onStart(onOTAStart);
  ElegantOTA.onProgress(onOTAProgress);
  ElegantOTA.onEnd(onOTAEnd);

  // This is the mainloop for the second thread (and will never exit)
  while(true)
  {
    networkState.networkConnected = WiFi.status() == WL_CONNECTED;
    
    if ( WiFi.status() ==  WL_CONNECTED ) 
    {
      // Allow the MQTT client to do 'keep alives' etc      
      bool ret =  mqttClient.loop(); // returns false if MQTT not connected
      yield(); 

      if(!ret)
      {
        reconnectMQTT(1);
        networkState.mqttConnected = false;
        tftState.isDirty = true; 
      }

    }
    else
    {
      // wifi down, reconnect here
      WiFi.begin();    
      int WLcount = 0;
      while (WiFi.status() != WL_CONNECTED && WLcount < 200 ) 
      {
        delay( 100 );
        ++WLcount;
      }      
    }  

    delay(50);
  }
}


/// Called when new message received over MQTT
void mqtt_callback(char* topic, byte* payload, unsigned int length) {
  Serial.print("Message arrived [");
  Serial.print(topic);
  Serial.print("] ");
  for (int i=0;i<length;i++) {
    Serial.print((char)payload[i]);
  }
  Serial.println();
}

// Attempt to reconnect to MQTT - this will block whilst trying "retryCount" times and then return
void reconnectMQTT(int retryCount=5) {
  // Loop until we're reconnected
  while (!mqttClient.connected() && retryCount>0)
  {
    Serial.println("MQTT re-connecting");
    // Attempt to connect
    if (mqttClient.connect(networkState.mqtt_client_id, networkState.mqtt_user.c_str(), networkState.mqtt_password.c_str())) {
      Serial.println("connected");
    } 
    else
    {
      Serial.println("MQTT fail: " + String(mqttClient.state()));
      // Wait before retrying
      delay(800);
    }
    --retryCount;
  }
}



// If MQTT server parameters have been defined then we try and connect
bool setup_mqtt()
{
  if(networkState.mqtt_server[0] == '0' && networkState.mqtt_server[1] == '.')
  {
    Serial.println("MQTT fail, no server is defined");
    
    return false;
  }

  if(networkState.mqtt_user[0] == '\0')
  {
    Serial.println("MQTT fail, no user is defined");
    return false;
  }

  Serial.println("MQTT -> user: " + String(networkState.mqtt_user) + " Server: " + networkState.mqtt_server.c_str());
  mqttClient.setServer(networkState.mqtt_server.c_str(), 1883);
  mqttClient.setCallback(mqtt_callback);

  uint64_t chipid = ESP.getEfuseMac();

  snprintf(networkState.mqtt_client_id, 23, "ESP32-%08X", (uint32_t)chipid);
  Serial.println(String("MQTT client id: ") + networkState.mqtt_client_id);

  // Ensure we use a random "client id" - Mosquitto MQTT server will disconnect if two clients connect with same id
  
  if(!mqttClient.connect(networkState.mqtt_client_id, networkState.mqtt_user.c_str(), networkState.mqtt_password.c_str()))
  {
    Serial.println("MQTT fail");
    return false;
  }
  
  Serial.println("MQTT ok");
  return true;
}


void extractPZEM_Info()
{
#ifdef PZEM_V3

  Serial.println(String(" IS CONN") + String(pzem.isConnected()));
  tftState.pzemAddress = pzem.getAddress();

  // Read the data from the sensor
  tftState.voltage    = pzem.voltage();
  tftState.current    = pzem.current();
  tftState.power      = pzem.power();
  tftState.energy     = pzem.energy();
  tftState.frequency  = pzem.frequency();
  tftState.pf         = pzem.pf();
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

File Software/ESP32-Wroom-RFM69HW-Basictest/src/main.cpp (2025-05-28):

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
// Licence can be viewed at                               
// http://www.gnu.org/licenses/gpl-3.0.txt
//
// Please maintain this license information along with authorship
// and copyright notices in any redistribution of this code
// **********************************************************************************
#include <RFM69.h>         //get it here: https://www.github.com/lowpowerlab/rfm69
#include <RFM69_ATC.h>     //get it here: https://www.github.com/lowpowerlab/rfm69
#include <SPI.h>           //comes with Arduino IDE (www.arduino.cc)
//#include <SPIFlash.h>      //get it here: https://www.github.com/lowpowerlab/spiflash
#include <Wire.h>          //comes with Arduino

#include <Adafruit_GFX.h>
#include <Adafruit_ST7789.h> // Hardware-specific library for ST7789

//****************************************************************************************************************
//**** IMPORTANT RADIO SETTINGS - YOU MUST CHANGE/CONFIGURE TO MATCH YOUR HARDWARE TRANSCEIVER CONFIGURATION! ****
//****************************************************************************************************************
#define GATEWAYID     1     //ID of  your main/gateway/receiver node (can be any ID but good to keep this as 1 or an easy to remember number)
#define NODEID        2  //88    //unique for each node on same network
#define NETWORKID     100  //the same on all nodes that talk to each other
//Match frequency to the hardware version of the radio on your Moteino (uncomment one):
#define FREQUENCY     RF69_433MHZ
//#define FREQUENCY     RF69_868MHZ
//#define FREQUENCY     RF69_915MHZ
#define IS_RFM69HW_HCW  //uncomment only for RFM69HW/HCW! Leave out if you have RFM69W/CW!
#define ENCRYPTKEY    "sampleEncryptKey" //exactly the same 16 characters/bytes on all nodes!
#define ENABLE_ATC    //comment out this line to disable AUTO TRANSMISSION CONTROL
#define ATC_RSSI      -75
//#define ENABLE_BME280 //uncomment to allow reading the BME280 (if present)
//*********************************************************************************************
#define ACK_TIME      30  // max # of ms to wait for an ack
#define ONBOARDLED     9  // Moteinos have LEDs on D9
//#define LED            5  // MotionOLEDMote has an external LED on D5
//#define MOTION_PIN     3  // D3
//#define MOTION_IRQ     1  // hardware interrupt 1 (D3) - where motion sensors OUTput is connected, this will generate an interrupt every time there is MOTION
//#define BATT_MONITOR  A7  // Sense VBAT_COND signal (when powered externally should read ~3.25v/3.3v (1000-1023), when external power is cutoff it should start reading around 2.85v/3.3v * 1023 ~= 883 (ratio given by 10k+4.7K divider from VBAT_COND = 1.47 multiplier)
//#define BATT_FORMULA(reading) reading * 0.00322 * 1.49 // >>> fine tune this parameter to match your voltage when fully charged
                                                       // details on how this works: https://lowpowerlab.com/forum/index.php/topic,1206.0.html
#define DUPLICATE_INTERVAL 20000 //avoid duplicates in 55second intervals (ie mailman sometimes spends 30+ seconds at mailbox)
#define BATT_INTERVAL  300000  // read and report battery voltage every this many ms (approx)

#define SERIAL_EN             //comment this out when deploying to an installed Mote to save a few KB of sketch size
#define SERIAL_BAUD    115200
#ifdef SERIAL_EN
#define DEBUG(input)   {Serial.print(input); }
#define DEBUGln(input) {Serial.println(input); }
#define DEBUGFlush() { Serial.flush(); }
#else
#define DEBUG(input);
#define DEBUGln(input);
#define DEBUGFlush();
#endif


//#define FLASH_SS      8 // and FLASH SS on D8 on regular Moteinos (D23 on MoteinoMEGA)
//SPIFlash flash(FLASH_SS, 0xEF30); //EF30 for 4mbit  Windbond chip (W25X40CL)


volatile boolean motionDetected=false;
float batteryVolts = 5;
char BATstr[10]; //longest battery voltage reading message = 9chars
char sendBuf[32];
byte sendLen;



///////// Parameters needed for the TFT screen - to display debug diagnostics

// On the ESP32 there are two HARDWARE SPI ports - one called VSPI (default) and the other HSPI
// On my board, HSPI will be used for the TFT LCD and VSPI is used for RFM68HW 
// The board is using the STANDARD defined pins for HSPI (so in a way the following defines are redundant)
#define HSPI_MISO   12
#define HSPI_MOSI   13
#define HSPI_SCLK   14
#define HSPI_SS     15

// This is a board specific pin number - i.e. for this TFT we need a DC pin and I have designed the PCB with it on GPIO 2
#define TFT_DC 2

#define RFM69_CS  5
#define RFM69_DIO  4

#define RF69_IRQ_PIN RFM69_DIO

/// Note: The TFT / SPI api has param for  a reset pin - but for this board I have connected RESET of TFT to the "enable" pin of the ESP32 - i.e. it resets upon startup

//uninitalised pointers to SPI objects
SPIClass * vspi = NULL;
SPIClass * hspi = NULL;
Adafruit_ST7789 * tft = NULL; 

#ifdef ENABLE_ATC
  RFM69_ATC* radio;
#else
  RFM69* radio;
#endif

/**
 * INITIALISATION 
 * 
 */
void setup() {
  Serial.begin(SERIAL_BAUD);

  /////// TFT SCREEN initialisation

  //initialise an instance of the SPIClass attached to HSPI respectively
  hspi = new SPIClass(HSPI);
  vspi = new SPIClass(VSPI); //SPI bus normally attached to pins 5, 18, 19 and 23,
  
  //initialise hspi with default pins
  //SCLK = 14, MISO = 12, MOSI = 13, SS = 15
  hspi->begin();

  //SCLK = 18, MISO = 19, MOSI = 23, SS = 5
  vspi->begin();

  tft = new Adafruit_ST7789(hspi,HSPI_SS, TFT_DC, -1);
  tft->init(240, 280);           // Init ST7789 280x240
  // default rotation is if the screen was rotated 90 deg clockwise
  // rotation 1 is upside down
  // rotation 2 is rotated 90 anti-clockwise
  tft->setRotation(3);

  tft->fillScreen(ST77XX_RED);//
  Serial.println(F("TFT initialised"));

  tft->setCursor(0, 50);
  tft->setTextColor(ST77XX_WHITE);
  tft->setTextSize(2);
  tft->println("Screen initialised ");


  radio = new RFM69_ATC(RFM69_CS,RF69_IRQ_PIN,true, vspi);

  bool ret = radio->initialize(FREQUENCY,NODEID,NETWORKID);
  if(ret)
  {
    tft->println("Radio initialised OK");
    radio->readAllRegs();
  }
  else
    tft->println("Radio initialised FAILED");

#ifdef IS_RFM69HW_HCW
  radio->setHighPower(); //must include this only for RFM69HW/HCW!
#endif
  tft->println("Set high power ");
  radio->encrypt(ENCRYPTKEY);
  tft->println("Encrypt on ");
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

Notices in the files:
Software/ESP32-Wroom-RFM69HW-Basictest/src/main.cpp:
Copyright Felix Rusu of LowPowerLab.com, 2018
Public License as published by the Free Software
